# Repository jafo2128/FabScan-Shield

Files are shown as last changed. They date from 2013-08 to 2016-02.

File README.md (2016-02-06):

# FabScan-Shield
The FabScan-Shield is a plug-on module for Arduino/Genuino to drive Stepper and Servo Motors or to build a 3D Laser Scanner.

Infos about the FabScan 3D-Scanner: http://hci.rwth-aachen.de/fabscan

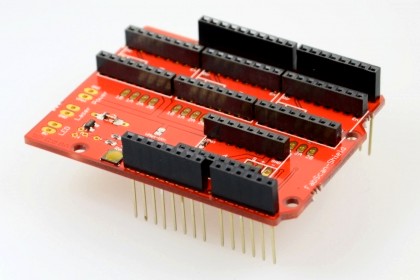
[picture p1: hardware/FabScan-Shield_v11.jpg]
FabScan-Shield (http://www.watterott.com/en/Arduino-FabScan-Shield)


## Shop
* [FabScan-Shield](http://www.watterott.com/en/Arduino-FabScan-Shield)
* [FabScan Cube Kit with USB camera](http://www.watterott.com/en/FabScan-Cube-complete-Kit)
* [FabScan Cube Kit without USB camera](http://www.watterott.com/en/FabScan-Cube-Electronics)
* [FabScan Cube Wood Parts](http://www.watterott.com/en/Fabscan-CUBE-Kit)
* [FabScan Cube Screw Set](http://www.watterott.com/en/FabScan-Cube-Screw-set)

## Features
* Drive up to 3 (v1.0) or 4 (v1.1) stepper motors (requires Pololu A4988 or StepStick) or servo motors
* Compatible with FabScan (3D Laser Scanner)

## Hardware and Software
* [Schematics + Layout](https://github.com/watterott/FabScan-Shield/tree/master/hardware)
* [Arduino Examples](https://github.com/watterott/FabScan-Shield/tree/master/software)
* FabScan: [Shield Assembly Instructions](http://hci.rwth-aachen.de/fabscan_shield), [Assembly Instructions](http://32b.it/assembly-fabscan-by-wetterott-my-personal-instruction-guide/), [Scanning Instructions](http://www.mariolukas.de/2014/07/scannen-mit-dem-fabscan/)

Finally words from us Archivers and Developers.. 

##### Donate

People from time to time wish to donate a little money. Donating won't get you anything special, other than a warm feeling inside, and possibly urge me to produce more freely available material for interesting projects. You can donate via [PayPal](https://www.paypal.com), just click [donate](https://www.paypal.com/cgi-bin/webscr?cmd=_s-xclick&hosted_button_id=3PXVSLXFBS45E) button available below - it will redirect you to the secured PayPal page where you can provide donation amount (there is no minimal value). Any donations are apreciated greatly, and we thank you all in advance for your support along the ways..



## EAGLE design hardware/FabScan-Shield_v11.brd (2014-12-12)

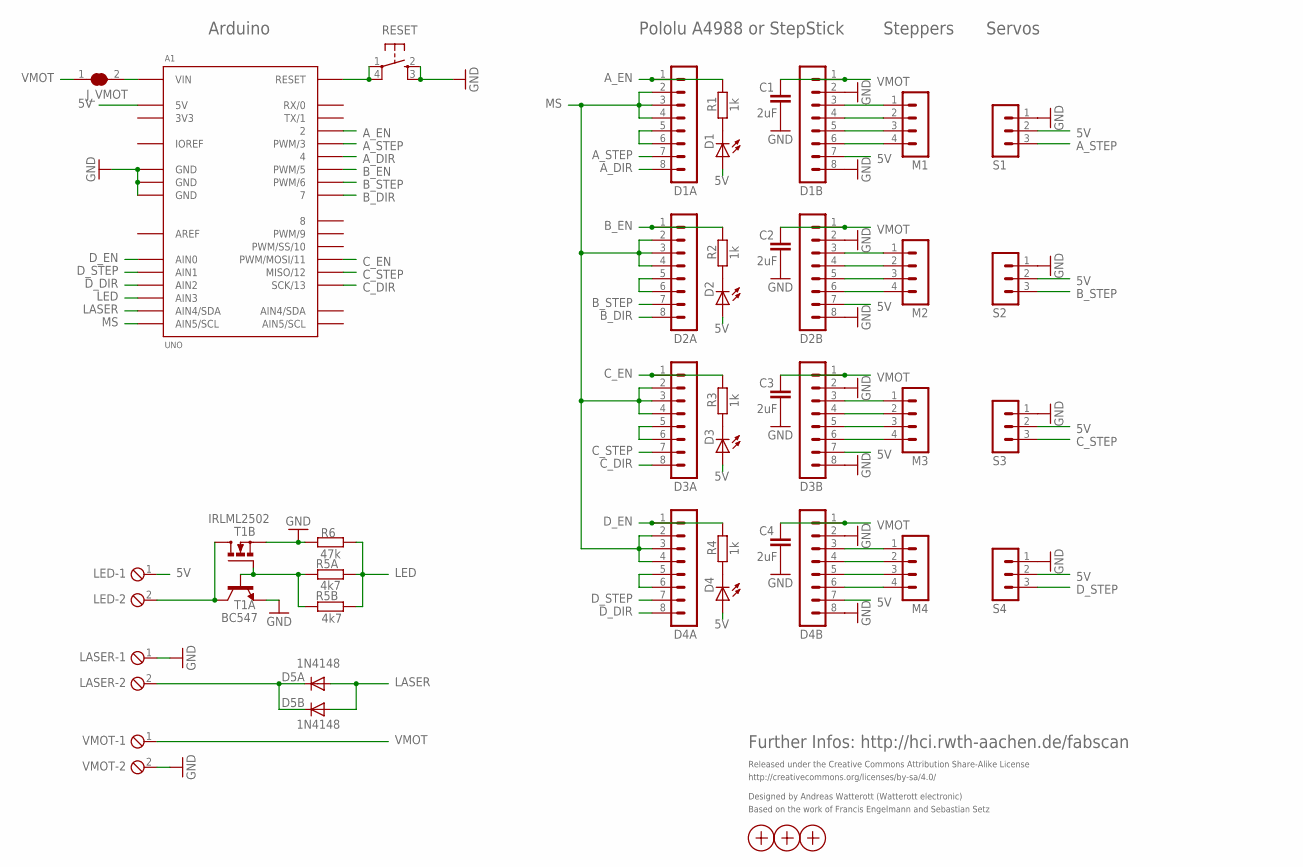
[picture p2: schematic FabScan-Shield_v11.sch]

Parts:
A1: UNO
C1, C2, C3, C4: 2uF; C0603
D1, D2, D3, D4: LEDCHIPLED_0603; CHIPLED_0603
D1A, D1B, D2A, D2B, D3A, D3B, D4A, D4B: MA08-1
D5A: 1N4148; DO35-7
D5B: 1N4148; SOD106-R
J_VMOT: SJ
LASER: MPT2; 2POL254
LED: MPT2; 2POL254
M1, M2, M3, M4: MA04-1
R1, R2, R3, R4: 1k; R0603
R5A: 4k7; 0204/7
R5B: 4k7; R0603
R6: 47k; R0603
RESET: SW_SMDS; SW_SMD4
S1, S2, S3, S4: MA03-1
T1A: BC547; TO92
T1B: IRLML2502; MICRO3
VMOT: MPT2; 2POL254
X1, X2, X3: PASSER

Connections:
3V3: A1.3V3
5V: A1.5V, D1.A, D1B.7, D2.A, D2B.7, D3.A, D3B.7, D4.A, D4B.7, LED.1, S1.2, S2.2, S3.2, S4.2
AREF: A1.AREF
A_1A: D1B.5, M1.3
A_1B: D1B.6, M1.4
A_2A: D1B.4, M1.2
A_2B: D1B.3, M1.1
A_DIR: A1.4, D1A.8
A_EN: A1.2, D1A.1, R1.1
A_RST: D1A.5, D1A.6
A_STEP: A1.3 (PWM/3), D1A.7, S1.3
B_1A: D2B.5, M2.3
B_1B: D2B.6, M2.4
B_2A: D2B.4, M2.2
B_2B: D2B.3, M2.1
B_DIR: A1.7, D2A.8
B_EN: A1.5 (PWM/5), D2A.1, R2.1
B_STEP: A1.6 (PWM/6), D2A.7, S2.3
C_1A: D3B.5, M3.3
C_1B: D3B.6, M3.4
C_2A: D3B.4, M3.2
C_2B: D3B.3, M3.1
C_DIR: A1.13 (SCK/13), D3A.8
C_EN: A1.11 (PWM/MOSI/11), D3A.1, R3.1
C_STEP: A1.12 (MISO/12), D3A.7, S3.3
D_1A: D4B.5, M4.3
D_1B: D4B.6, M4.4
D_2A: D4B.4, M4.2
D_2B: D4B.3, M4.1
D_DIR: A1.AIN2, D4A.8
D_EN: A1.AIN0, D4A.1, R4.1
D_STEP: A1.AIN1, D4A.7, S4.3
GND: A1.GND@1 (GND), A1.GND@2 (GND), A1.GND@3 (GND), C1.2, C2.2, C3.2, C4.2, D1B.2, D1B.8, D2B.2, D2B.8, D3B.2, D3B.8, D4B.2, D4B.8, LASER.1, R6.2, RESET.2 (S), RESET.3 (S1), S1.1, S2.1, S3.1, S4.1, T1A.1 (E), T1B.2 (S), VMOT.2
IOREF: A1.IOREF
LASER: A1.AIN4 (AIN4/SDA), D5A.A, D5B.A
LED: A1.AIN3, R5A.1, R5B.2, R6.1
MS: A1.AIN5 (AIN5/SCL), D1A.2, D1A.3, D1A.4, D2A.2, D2A.3, D2A.4, D3A.2, D3A.3, D3A.4, D4A.2, D4A.3, D4A.4
unnamed: D5A.C, D5B.C, LASER.2
unnamed: D1.C, R1.2
unnamed: D2.C, R2.2
unnamed: D3.C, R3.2
unnamed: D4A.5, D4A.6
unnamed: LED.2, T1A.3 (C), T1B.3 (D)
unnamed: D4.C, R4.2
unnamed: R5A.2, R5B.1, T1A.2 (B), T1B.1 (G)
unnamed: D2A.5, D2A.6
unnamed: D3A.5, D3A.6
RST: A1.RST (RESET), RESET.1, RESET.4 (P1)
VIN: A1.VIN, J_VMOT.2
VMOT: C1.1, C2.1, C3.1, C4.1, D1B.1, D2B.1, D3B.1, D4B.1, J_VMOT.1, VMOT.1

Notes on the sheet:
Released under the Creative Commons Attribution Share-Alike License
http://creativecommons.org/licenses/by-sa/4.0/
Designed by Andreas Watterott (Watterott electronic)
Further Infos: http://hci.rwth-aachen.de/fabscan
Based on the work of Francis Engelmann and Sebastian Setz
Servos
Steppers
Arduino
Pololu A4988 or StepStick

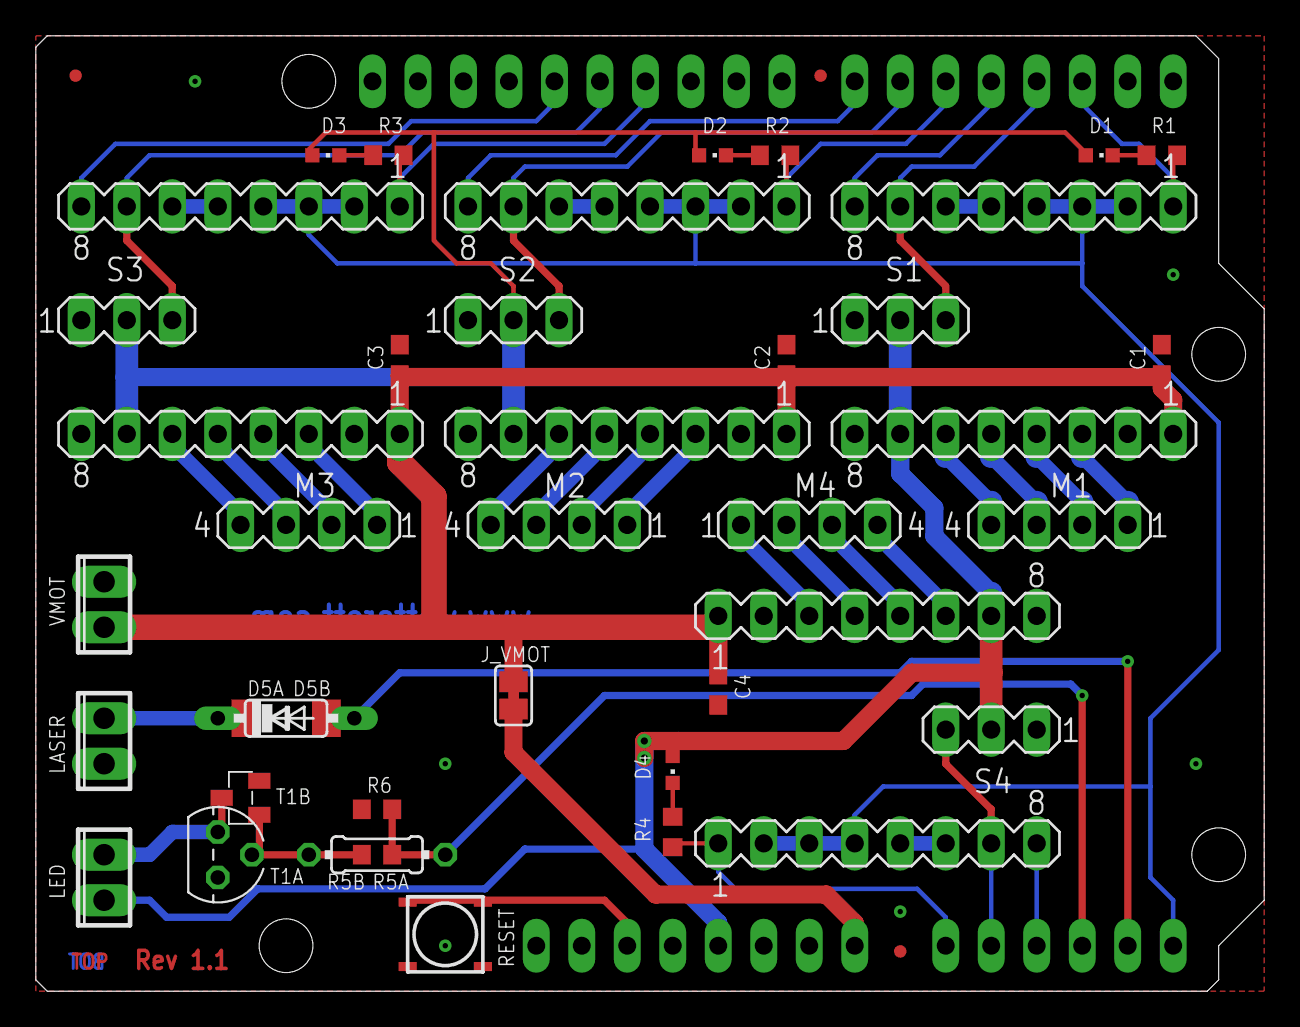
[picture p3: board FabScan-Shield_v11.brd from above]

Board: 2 copper layers, 68.6 x 53.3 mm, 44 parts (0 on the bottom side), 47 nets.

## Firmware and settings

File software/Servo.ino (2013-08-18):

/*
  Using a Servo Motor with FabScan-Shield.
  Further infos: http://arduino.cc/en/Reference/Servo
*/

#include <Servo.h> 

Servo myservo;

void setup()
{ 
  myservo.attach(3); //3 or 6 or 12 or A1
} 

void loop() 
{ 
  myservo.write(0); //0...180
  delay(2000);
  myservo.write(90);
  delay(2000);
  myservo.write(180);
  delay(2000);
}

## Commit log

2012-11-26 added schematic and layout files
    [FabScan-Shield_v10.brd, FabScan-Shield_v10.sch]
2012-12-07 upated schematics
    [FabScan-Shield_v10.sch]
2013-01-16 added Arduino examples
2013-03-26 added assembly infos updated readme + projects
2013-08-18 added pcb v1.1
    [FabScan-Shield_v11.brd, FabScan-Shield_v11.sch]
2014-08-15 updated schematic and layout files
    [FabScan-Shield_v10.brd, FabScan-Shield_v10.sch, FabScan-Shield_v11.brd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]
2014-08-21 updated layout and schematics
    [FabScan-Shield_v10.brd, FabScan-Shield_v15.brd, FabScan-Shield_v15.sch]
2014-09-18 removed beta layout
    [FabScan-Shield_v15.brd, FabScan-Shield_v15.sch]
2014-10-24 added assembly guide
2014-11-06 cleaned up schematics and layout
    [FabScan-Shield_v10.brd, FabScan-Shield_v10.sch, FabScan-Shield_v11.brd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]
2015-05-23 updated schematics
2015-08-21 changed path structure
    [FabScan-Shield_v10.brd, FabScan-Shield_v10.sch, FabScan-Shield_v11.brd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]
